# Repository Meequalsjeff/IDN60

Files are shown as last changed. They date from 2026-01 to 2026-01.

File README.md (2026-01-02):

# IDN60 — IDB60 Homage Case (IDB60 Mount Compatible )

A 7° 60% keyboard case designed as an homage to the IDB60 and built around the **IDB60 mounting ecosystem** (plateless o-ring bottom mount).  
**WKL only** for now.

> Note: There are **slight changes to bezel thickness** compared to real-life prototype photos.

---

## Specs

- **Layout:** 7° 60%
- **Case size:** **W 296.191 mm × L 111.20 mm**
- **Height:** Front **18.56 mm**, Back **33.08 mm**
- **Mount:** **IDB60 mount** (plateless o-ring bottom mount)
- **Weight:** Internal brass
- **Alignment pillars:** 4
- **Variant:** **WKL only** as of now

## IDB MOUNT 

    https://imgur.com/a/RQBupM5

## Proto images

  

  

  

  

  

  

## Digital images - I can't render :( 

   

   

   

   

---

## O-Rings

Same as IDB60:

- **5mm OD**
- **1mm thickness**
- **3mm ID**

---

## Hardware

### Case Screws (x8)
Low profile socket head:
- **M3 × 0.5**
- **8mm length**
- McMaster: https://www.mcmaster.com/93070A064/

### Countersunk Screws (x4)
Flathead countersunk:
- **M2 × 0.4**
- **4mm length**
- McMaster: https://www.mcmaster.com/91294A002/



---

## PCB Compatibility

- Supports **IDB PCB / open-source 60% PCBs** 
- **Tested with 1.2mm PCB thickness**
- Manufacture and use at your own risk.

Open source IDB60 PCBs : 

Aftermarket idb60 PCB by @mfchill: https://github.com/dannyjim-ml/idb60-ReplacementPCB
Aftermarket idb60 PCB by @kakan: https://github.com/Ludwig-van-Keebhoven/Aftermarket_idb60
IDB Reborn by @Mattelec: https://github.com/4pplet/IDB_Reborn
---

## Feet

Use Geon Works feet:
- **https://geon.works/products/feet-284**
- **2 pieces total** (one for the top, one for the bottom)



---

## Files

This repo is organized into the following folders:

- **`IDN60 SOURCE- AUTODESK FUSION FILES/`**  
  Native Autodesk Fusion design files (recommended if you want to modify the geometry).

- **`IDN60 EXCHANGE - STEP FILES/`**  
  STEP exports for compatibility with most CAD software.

- **`IDN60 STEL:FABRICATION - STL + TECHNICAL DRAWING/`**  
  Manufacturing-ready exports:
  - STL files for prints, mockups, and basic fit checks  
  - Technical drawings for machining / inspection

- **`IDN60 PREVIEW - AUTODESK FILE BUT ALL  INCLUDING ORINGS, SCREWS, FEET, ETC/`**  
  Full assembly preview file including hardware and accessories (o-rings, screws, feet, etc.) for visualization and fitment reference.

---

## Notes / Disclaimer
This is an open design and provided as-is. Fitment can vary depending on manufacturing tolerances, PCB thickness, and build choices. Double-check dimensions before machining or ordering parts. Especially for 3DP.
DM me on Discord @ meequalsjeff for help

## CREDITs
Thanks to PNGU for the design of the IDB60 that this is based on.  
Thanks to 0xenra for countless hours of help

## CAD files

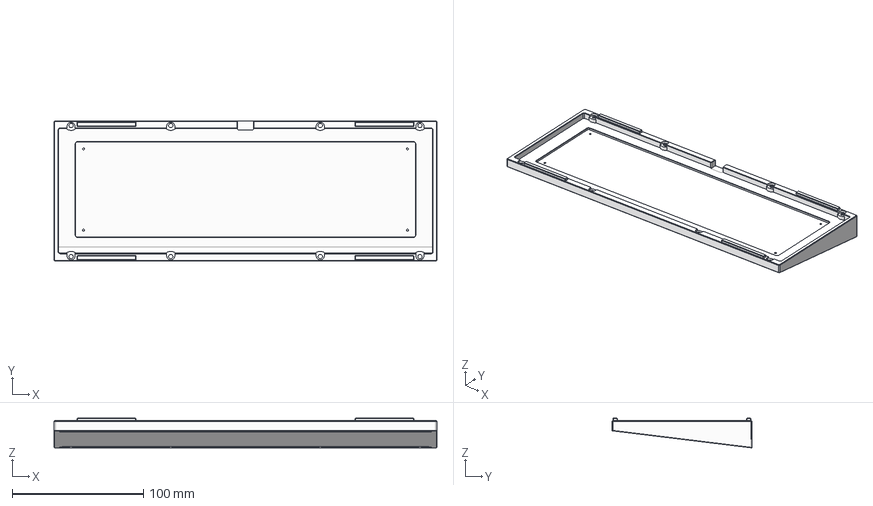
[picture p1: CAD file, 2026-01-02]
IDN60/IDN60 EXCHANGE/IDN60_BOTTOM.step
292.1 x 107.1 x 22.7 mm

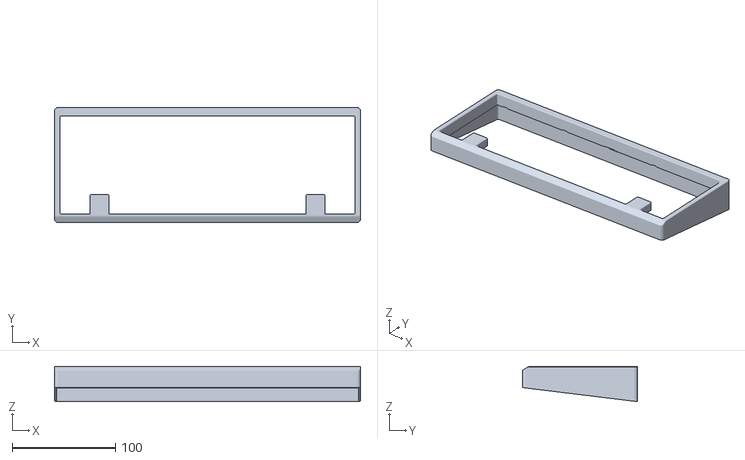
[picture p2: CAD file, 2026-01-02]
IDN60/IDN60 STL:FABRICATION/IDN60_TOP.stl
296.2 x 111.2 x 34.0

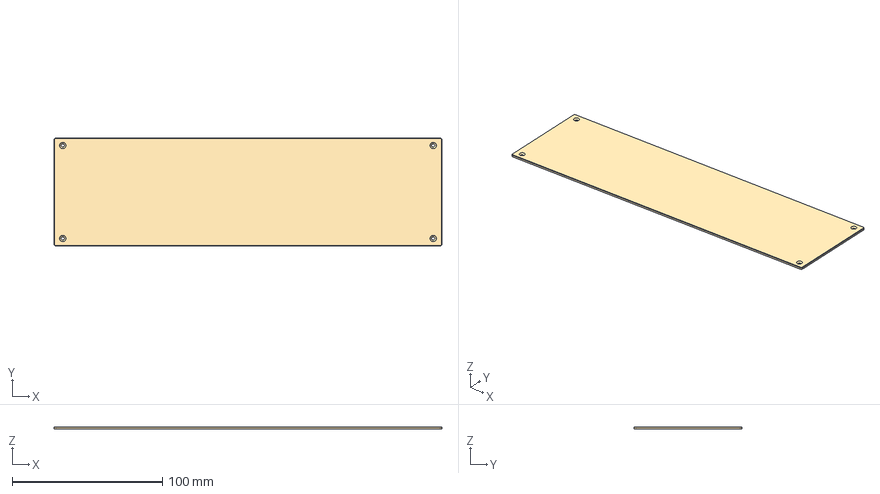
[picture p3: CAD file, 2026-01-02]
IDN60/IDN60 EXCHANGE/IDN60_INT_WEIGHT.step
258.7 x 72.0 x 1.50 mm

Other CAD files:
IDN60/IDN60 STL:FABRICATION/IDN60_BOTTOM.stl
IDN60/IDN60 EXCHANGE/IDN60_TOP.step
IDN60/IDN60 STL:FABRICATION/IDN60_INT_WEIGHT.stl
IDN60/IDN60 SOURCE/IDN60_BOTTOM.f3d
IDN60/IDN60 SOURCE/IDN60_INT_WEIGHT.f3d
IDN60/IDN60 SOURCE/IDN60_TOP.f3d
IDN60/PREVIEW/FULLIDN60.f3d

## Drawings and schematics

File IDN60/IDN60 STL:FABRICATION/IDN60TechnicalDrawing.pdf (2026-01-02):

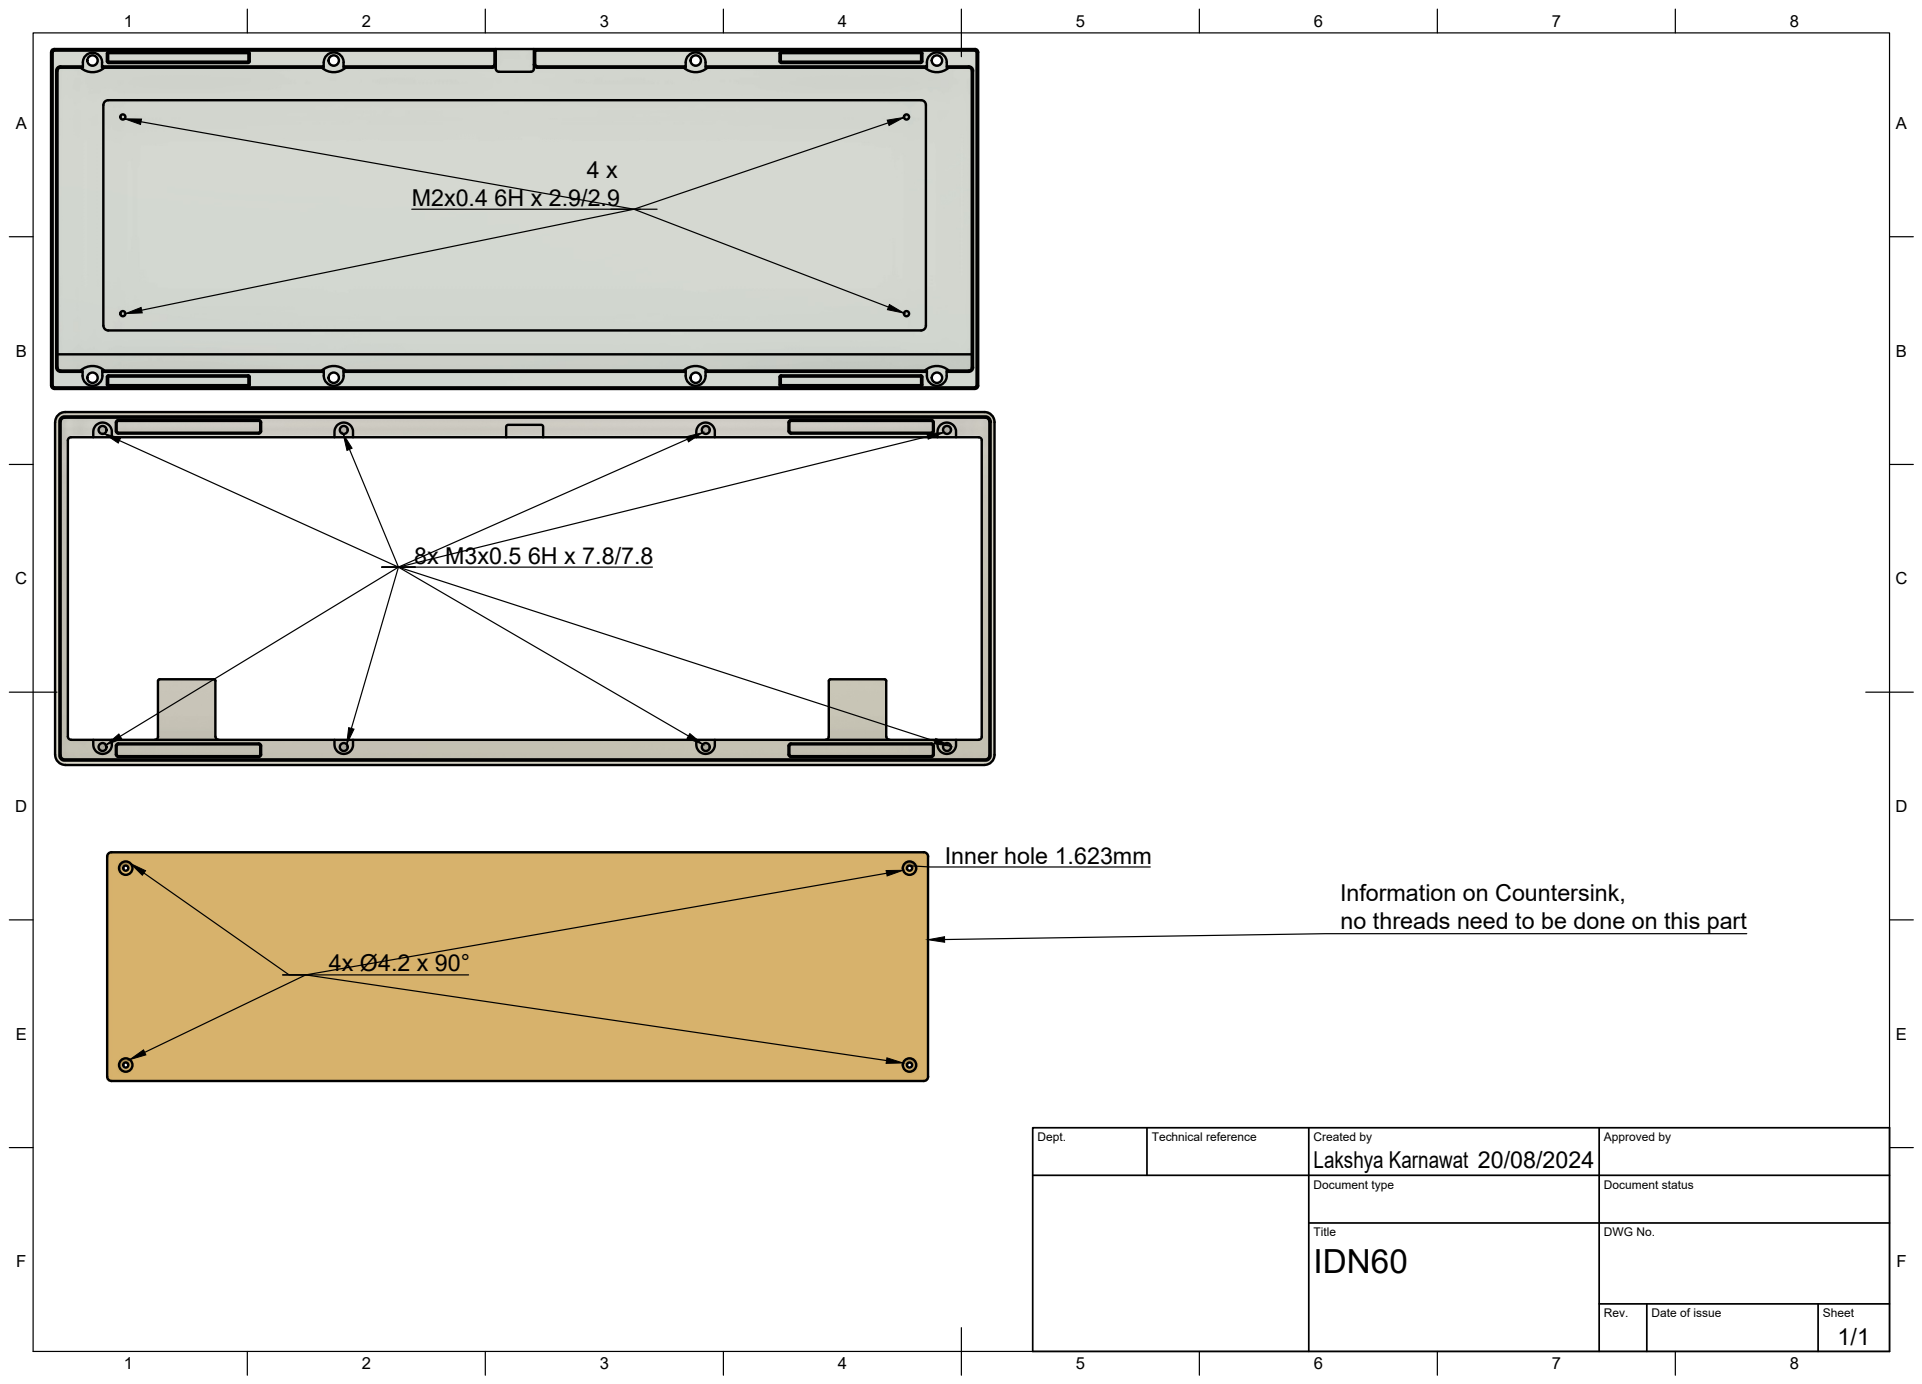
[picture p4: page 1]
Title; DWG No.; Rev.; Date of issue; Sheet; Inner hole 1.623mm

Information on Countersink,
no threads need to be done on this part

Dept. | Technical reference | Created by Lakshya Karnawat 20/08/2024 | Approved by

Document type | Document status
